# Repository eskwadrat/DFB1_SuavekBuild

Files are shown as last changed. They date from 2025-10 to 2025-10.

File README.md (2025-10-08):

## David's Falcon Booster (DFB) with Suavek Build update - described down below in Suavek UPDATE section. 

#### An attempt to build a low-cost memory expansion and accelerator board for the Atari Falcon.

The primary goals of the project are to:

* Be a plug-in board requiring no soldering on the Falcon;
* Increase available RAM beyond the 14MB the stock Falcon can be expanded to;
* Be low cost;
* Provide some acceleration;
* Allow the PSU to remain in the case;
* Be open source.

Some development narration on this project is provided in the [Wiki](https://github.com/dh219/DFB/wiki).

Firmware source (ISE), board design files (KiCAD) and any source for support programs are published at each release.

#### Capabilities

As of 2024 the published firmware supports 64 (2x32) or 128 (2x64) MB of TT-RAM.

It supports only a PGA128 MC68030. The board has been tested between 32 and 50MHz with the CPU normally being the limiting factor.

The FPU is optional and can be run at half the CPU speed, or with an independent oscillator. This is configured by a resistor placement choice.

The Falcon's on-board FPU, if fitted, should be removed to prevent bus conflicts.

---

*Copyright 2020-24 D Henderson, released under GPL2.0*

#### Suavek UPDATE 

This is David Henderson Falcon accelerator design for Atari Falcon 030. 
Original design Github repository link: https://github.com/dh219/DFB

This fork contains David’s KiCad files for the PCB design, in which I slightly modified the silkscreen layer to make selected reference designators visible outside the component footprints. This ensures that when the board is assembled, the markings remain clearly visible.

Additional silkscreen cleanup involved removing silkscreen covering certain through-hole pads. I have no idea how these ended up there. Normally, such markings are flagged and removed by a CAM engineer at the PCB shop during fabrication if present, but I decided to correct them directly in the source file to avoid the risk of them being left in place. If manufactured that way, the silkscreen paint could cover plated-through holes, rendering the board unusable for assembly.

No other design changes were made to the original DFB1 board. There were no copper or component modifications of any kind.

The fork also includes a CPLD modification I introduced and tested to enable “dual boot” functionality for the DFB1’s on-board Flash.
Boot selection is controlled using the OPTION1 section of the J2 jumper. When the jumper is closed, the computer boots from Flash Bank 0 (A19 = 0); when open, it boots from Bank 1 (A19 = 1).
This mod is achieved by patching the original Verilog code for the CPLD, where I repurposed the OPTION1 jumper from its original RAM-size selection function to serve the new dual-boot feature. Since my DFB1 build is equipped with 64 MB of physical RAM, the jumper setting is no longer needed to select memory size as it would not change the installed RAM on the PCB. Therefore, we lose no functionality by repurposing the Option1 jumper and instead gain a useful new feature.

Steve Suavek, 10/08/2025
______________

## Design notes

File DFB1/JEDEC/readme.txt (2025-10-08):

This mod enables use of A19 address line to switch two 512kB banks of 1MB Flash on board of DFB1 to have dual boot. 

The mod is using Options1 jumper which was repurposed from selecting 64/128MB Fast RAM size to switching Flash ROM boot banks.

To bypass 64/128MB Option1 switch, I created two separate .jed files to flash in CPLD with 64MB or 128MB RAM installed on the DFB1 board. 

With this mod Option1 jumper allows to switch banks. It can be wired to external switch for user convenience. 

_________________________________________
mod by Steve Suavek, 2025-10-07

I am not responsible for any damages to your equipment or software if you decided to use this mod. All responsibility to validate this mod is upon you if you choose to use it. Thanks.

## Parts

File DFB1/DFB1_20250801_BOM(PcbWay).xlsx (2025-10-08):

 |  |  | DFB1_20250801 BOM
Item # | *Designator | *Qty | Manufacturer | *Mfg Part # | Description / Value | *Package/Footprint | Type | Your Instructions / Notes
1 | C22,C10,C19,C1,C3 | 5 | KEMET | C0805C106K4PACTU | CAP CER 10UF 10% 16V X5R 0805 | 0805 | SMT | or similar w/same parametrers listed in description
2 | C25,C24,C11,C9,C8,C23,C17,C16,C15,C14,C13,C12,C20,C18,C2,C7,C6,C4 | 18 | Yageo | CC0805KRX7R9BB104 | CAP CER 0.1UF 10% 50V X7R 0805 | 0805 | SMT | or similar w/same parametrers listed in description
3 | C5 | 1 | KEMET | C0805C331J5GACTU | CAP CER 330PF 5% 50V C0G/NP0 0805 | 0805 | SMT | or similar w/same parametrers listed in description
4 | D5,D4,D3,D2,D1 | 5 | Osram | LS R976-NR-1-0-20-R18 | LED RED DIFFUSED 100mcd 0805 SMD | 0805 | SMT | or similar w/same parametrers listed in description
5 | IC2,IC1 | 2 | ISSI | IS42S16160G-7TLI | IC DRAM 256MBIT PAR 54TSOP II | TSOP-II-54 | SMT | for 64MB Fast RAM
6 | IC6,IC5,IC4,IC3 | 4 | TI | SN74CB3T3245PW | IC BUS SWITCH 8 X 1:1 20-TSSOP | TSSOP-20 | SMT
7 | R10,R9,R8,R7,R6 | 5 | Stackpole | RNCP0805FTD1K00 | RES 1K OHM 1% 1/4W 0805 | 0805 | SMT | or similar w/same parametrers listed in description
8 | R12 | 1 | Stackpole | RNCP0805FTD4K75 | RES 4.75K OHM 1% 1/4W 0805 | 0805 | SMT | or similar w/same parametrers listed in description
9 | R15,R14,R13 | 3 | Stackpole | RNCP0805FTD10K0 | RES 10K OHM 1% 1/4W 0805 | 0805 | SMT | or similar w/same parametrers listed in description
10 | R18,R1,R20,R19,R16 | 5 | Stackpole | RNCP0805FTD33R2 | RES 33.2 OHM 1% 1/4W 0805 | 0805 | SMT | or similar w/same parametrers listed in description
11 | R3,R2 | 2 | Stackpole | RNCP0805FTD2K21 | RES 2.21K OHM 1% 1/4W 0805 | 0805 | SMT | or similar w/same parametrers listed in description
12 | RN7,RN6,RN5,RN4,RN2,RN1 | 6 | Yageo | TC164-JR-0710KL | RES ARRAY 4 RES 10K OHM 1206 | 1206, Concave | SMT | or similar w/same parametrers listed in description
13 | U1 | 1 | TI | LM1117MP-3.3/NOPB | IC REG LINEAR 3.3V 800MA SOT-223 | SOT-223 | SMT
14 | U4 | 1 | AMD | XC95288XL-10TQG144I | IC CPLD 288MC 10NS 144TQFP | TQFP144 | SMT
15 | U5 | 1 | Macronix | MX29F800CBTI-70G | IC FLASH 8MBIT PARALLEL 48TSOP | TSOP-I-48 | SMT
Need a quick and accurante quote? Need an efficient production? Please read SMT Ordering Necessary Files & Info in 1 minute. Thank you very much! (https://www.pcbway.com/smt_ordering_guide.html)
Click for Instructions on How to Create a BOM (https://www.pcbway.com/blog/PCB_Assembly/How_to_Build_a_BOM__Bill_Of_Materials_.html)

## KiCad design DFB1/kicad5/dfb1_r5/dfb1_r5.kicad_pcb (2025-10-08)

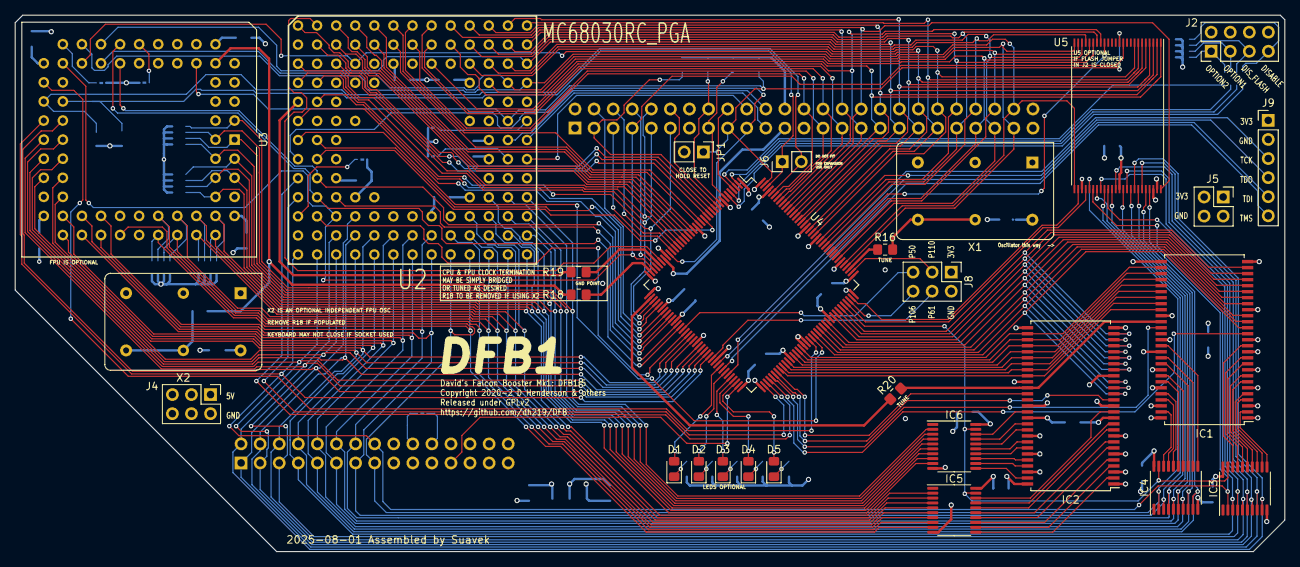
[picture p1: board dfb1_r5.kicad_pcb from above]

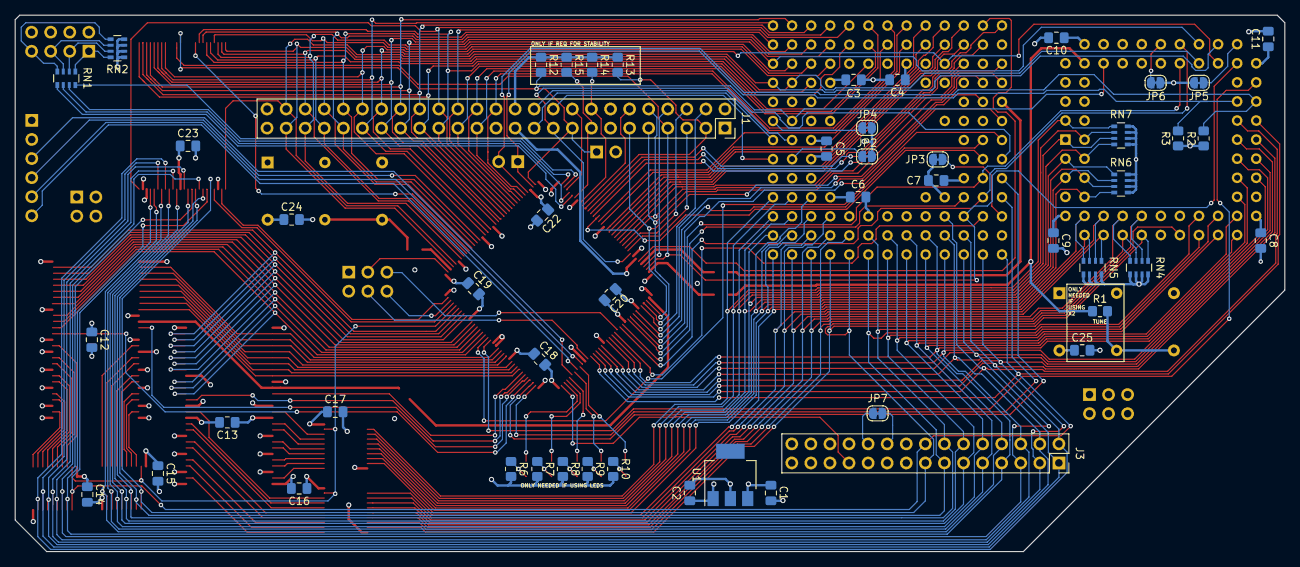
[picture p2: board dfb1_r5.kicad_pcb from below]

Board: 4 copper layers, 169.0 x 71.4 mm, 79 parts (51 on the bottom side), 204 nets.

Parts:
C1, C3, C10, C19, C22: 10u; C_0805_2012Metric_Pad1.18x1.45mm_HandSolder
C2, C4, C6, C7, C8, C9, C11, C12, C13, C14, C15, C16, C17, C18, C20, C23, C24, C25: 100n; C_0805_2012Metric_Pad1.18x1.45mm_HandSolder
C5: 330p; C_0805_2012Metric_Pad1.18x1.45mm_HandSolder
D1, D2, D3, D4, D5: LED; LED_0805_2012Metric_Pad1.15x1.40mm_HandSolder
IC1, IC2: IS42S16320D-7TL; TSOP-II-54_22.2x10.16mm_P0.8mm
IC3, IC4, IC5, IC6: SN74CB3T3245PW; TSSOP-20_4.4x6.5mm_P0.65mm
J1: Conn_01x50; PinSocket_2x25_P2.54mm_Vertical
J2: Conn_02x04_Odd_Even; PinHeader_2x04_P2.54mm_Vertical
J3: Conn_01x30; PinSocket_2x15_P2.54mm_Vertical
J4, J8: Conn_02x03_Odd_Even; PinHeader_2x03_P2.54mm_Vertical
J5: Conn_02x02_Odd_Even; PinHeader_2x02_P2.54mm_Vertical
J6: Conn_01x02_Female; PinHeader_1x02_P2.54mm_Vertical
J9: Conn_01x06_Male; PinHeader_1x06_P2.54mm_Vertical
JP1: Jumper_NO_Small; PinHeader_1x02_P2.54mm_Vertical
JP2, JP3, JP4, JP5, JP6, JP7: Jumper_NC_Small; SolderJumper-2_P1.3mm_Bridged_RoundedPad1.0x1.5mm_DAVID
R1, R16, R18, R19, R20: 33R NOMINAL; R_0805_2012Metric_Pad1.20x1.40mm_HandSolder
R2, R3: 2k2; R_0805_2012Metric_Pad1.20x1.40mm_HandSolder
R6, R7, R8, R9, R10: 1k; R_0805_2012Metric_Pad1.20x1.40mm_HandSolder
R12: 4k7 OPTION; R_0805_2012Metric_Pad1.20x1.40mm_HandSolder
R13, R14, R15: 10k OPTION; R_0805_2012Metric_Pad1.20x1.40mm_HandSolder
RN1, RN2, RN4, RN5, RN6, RN7: 10K; R_Array_Convex_4x0603
U1: LM1117-3.3; SOT-223
U2: MC68030RC_PGA
U3: MC68882; PLCC-68_THT-Socket
U4: XC95288XL-10TQG144I; TQFP-144_20x20mm_P0.5mm
U5: 29F800C-TSOP-48; TSOP-I-48_18.4x12mm_P0.5mm
X1, X2: CXO_DIP14_DIP8_DUAL; Oscillator_DIP-14-DUAL

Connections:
/68030/CDIS: JP2.1, U2.H12
/68030/CIIN: JP3.1, U2.L1
/68030/FPUSIZE: JP6.1, U3.18
/68030/FPU_A0: JP5.1, U3.26
/68030/MMUDIS: JP4.1, U2.F13
/CPLD/LED1: D1.2, U4.64
/CPLD/LED2: D2.2, U4.66
/CPLD/LED3: D3.2, U4.68
/CPLD/LED4: D4.2, U4.69
/CPLD/LED5: D5.2, U4.70
/CPLD/P50: J8.5, U4.50
/CPLD/P61: J8.4, U4.61
/CPLD/P106: J8.6, U4.106
/CPLD/P110: J8.3, U4.110
/CPLD/TCK: J9.3, U4.67
/CPLD/TDI: J9.5, U4.63
/CPLD/TDO: J9.4, U4.122
/CPLD/TMS: J9.6, U4.65
/CPUBGI: J3.22, JP7.2
/CPUBGO: J3.20, JP7.1
/ENABLE_J: J2.7, RN1.4, RN2.5
/EN_ALTRAM_J: J2.3, RN1.2, RN2.7
/EN_FLASH_J: J2.5, RN1.3, RN2.6
/OPTION_J: J2.1, RN1.1, RN2.8
A0: U2.A2, U4.31
A1: J1.48, U2.C4, U3.25, U4.113, U5.25
A2: J1.47, U2.D13, U3.24, U4.112, U5.24
A3: J1.46, U2.D12, U3.23, U4.116, U5.23
A4: J1.45, U2.C13, U3.22, U4.115, U5.22
A5: J1.44, U2.C12, U4.119, U5.21
A6: J1.43, U2.D11, U4.117, U5.20
A7: J1.42, U2.B13, U4.121, U5.19
A8: J1.41, U2.B12, U4.120, U5.18
A9: J1.40, U2.C11, U4.124, U5.8
A10: J1.39, U2.A13, U4.125, U5.7
A11: J1.38, U2.C10, U4.126, U5.6
A12: J1.37, U2.B11, U4.128, U5.5
A13: J1.36, U2.A12, U4.129, U5.4
A14: J1.35, U2.B10, U4.130, U5.3
A15: J1.34, U2.A11, U4.131, U5.2
A16: J1.33, U2.B9, U4.132, U5.1
A17: J1.32, U2.A10, U4.134, U5.48
A18: J1.31, U2.C8, U4.133, U5.17
A19: J1.30, U2.A9, U4.135
A20: J1.29, U2.B8, U4.136
A21: J1.28, U2.A8, U4.137
A22: J1.27, U2.B7, U4.138
A23: J1.26, U2.A7, U4.139
A24: U2.A6, U4.16
A25: U2.B6, U4.17
A26: U2.A5, U4.19
A27: U2.B5, U4.20
A28: U2.A4, U4.21
A29: U2.B4, U4.22
A30: U2.A3, U4.23
A31: U2.B3, U4.24
BA0: IC1.20, IC2.20, U4.96
BA1: IC1.21, IC2.21, U4.97
BMODE: J1.12, U4.10
CLKOSC: R16.1, U4.111
CPUCLK: R19.2, U2.E1
D0: IC6.2, RN7.1, U2.K13, U3.3
D1: IC6.3, RN7.2, U2.K12, U3.2
D2: IC6.4, RN7.3, U2.L13, U3.1
D3: IC6.6, RN7.4, U2.M13, U3.68
D4: IC6.5, RN6.1, U2.L12, U3.67
D5: IC6.7, RN6.3, U2.K11, U3.66
D6: IC6.8, RN6.2, U2.M12, U3.65
D7: IC6.9, RN6.4, U2.L11, U3.64
D8: IC5.2, RN5.4, U2.N13, U3.62
D9: IC5.3, RN5.3, U2.M11, U3.60
D10: IC5.4, RN5.2, U2.L10, U3.59
D11: IC5.5, RN5.1, U2.N12, U3.58
D12: IC5.6, RN4.4, U2.M10, U3.57
D13: IC5.7, RN4.3, U2.N11, U3.56
D14: IC5.8, RN4.2, U2.M9, U3.55
D15: IC5.9, RN4.1, U2.N10, U3.54
D16: IC4.2, J3.15, U2.N9, U3.50, U5.29
D17: IC4.4, J3.14, U2.M8, U3.49, U5.31
D18: IC4.3, J3.13, U2.N8, U3.48, U5.33
D19: IC4.5, J3.12, U2.N7, U3.47, U5.35
D20: IC4.6, J3.11, U2.M7, U3.46, U5.38
D21: IC4.7, J3.10, U2.N6, U3.45, U5.40
D22: IC4.8, J3.9, U2.M6, U3.44, U5.42
D23: IC4.9, J3.8, U2.N5, U3.42, U5.44
D24: IC3.3, J3.7, U2.M5, U3.40, U4.52, U5.30
D25: IC3.5, J3.6, U2.N4, U3.39, U4.53, U5.32
D26: IC3.4, J3.5, U2.N3, U3.38, U4.54, U5.34
D27: IC3.7, J3.4, U2.M4, U3.37, U4.56, U5.36
D28: IC3.6, J3.3, U2.N2, U3.36, U4.57, U5.39
D29: IC3.9, J3.2, U2.M3, U3.35, U4.58, U5.41
D30: IC3.8, J3.1, U2.L4, U3.34, U4.59, U5.43
D31: IC3.2, J3.16, U2.N1, U3.33, U4.60, U5.45
DQM0: IC1.15, U4.76
DQM1: IC1.39, U4.77
DQM2: IC2.15, U4.78
DQM3: IC2.39, U4.79
ENABLE: RN1.5, U4.6
EN_ALTRAM: RN1.7, U4.2
EN_FLASH: RN1.6, U4.5
FC0: J1.11, U2.D2, U4.39
FC1: J1.10, U2.C1, U4.25
FC2: J1.9, U2.D1, U4.40
FPUCLK: R1.1, R18.2, U3.11
GND: C1.2, C2.2, C3.2, C4.2, C5.2, C6.2, C7.2, C8.2, C9.2, C10.2, C11.2, C12.2, C13.2, C14.2, C15.2, C16.2, C17.2, C18.2, C19.2, C20.2, C22.2, C23.2, C24.2, C25.2, IC1.6, IC1.12, IC1.19, IC1.28, IC1.41, IC1.46, IC1.52, IC1.54, IC2.6, IC2.12, IC2.19, IC2.28, IC2.41, IC2.46, IC2.52, IC2.54, IC3.10, IC4.10, IC5.10, IC6.10, J1.1, J1.2, J2.2, J2.4, J2.6, J2.8, J3.17, J3.18, J3.19, J4.2, J4.4, J4.6, J5.2, J5.4, J8.2, J9.2, JP1.2, R6.2, R7.2, R8.2, R9.2, R10.2, U1.1, U2.C5, U2.C7, U2.C9, U2.E3, U2.E11, U2.F3, U2.G3, U2.G11, U2.J3, U2.J11, U2.L5, U2.L7, U2.L8, U2.L9, U3.5, U3.6, U3.7, U3.8, U3.9, U3.12, U3.14, U3.19, U3.30, U3.41, U3.51, U3.63, U4.18, U4.29, U4.36, U4.47, U4.62, U4.72, U4.89, U4.90, U4.99, U4.108, U4.114, U4.123, U4.144, U5.27, U5.46, X1.4, X1.7, X2.4, X2.7
KHZ500: J3.23, U4.71
MA0: IC1.23, IC2.23, U4.100
MA1: IC1.24, IC2.24, U4.101
MA2: IC1.25, IC2.25, U4.102
MA3: IC1.26, IC2.26, U4.103
MA4: IC1.29, IC2.29, U4.88
MA5: IC1.30, IC2.30, U4.87
MA6: IC1.31, IC2.31, U4.86
MA7: IC1.32, IC2.32, U4.85
MA8: IC1.33, IC2.33, U4.83
MA9: IC1.34, IC2.34, U4.82
MA10: IC1.22, IC2.22, U4.98
MA11: IC1.35, IC2.35, U4.81
MA12: IC1.36, IC2.36, U4.80
MD0: IC2.2, IC5.11
MD1: IC2.4, IC5.12
MD2: IC2.5, IC5.13
MD3: IC2.7, IC5.14
MD4: IC2.8, IC5.15
MD5: IC2.10, IC5.16
MD6: IC2.11, IC5.17
MD7: IC2.13, IC5.18
MD8: IC2.42, IC6.18
MD9: IC2.44, IC6.17
MD10: IC2.45, IC6.16
MD11: IC2.47, IC6.15
MD12: IC2.48, IC6.14
MD13: IC2.50, IC6.13
MD14: IC2.51, IC6.12
MD15: IC2.53, IC6.11
MD16: IC1.2, IC3.11
MD17: IC1.4, IC3.12
MD18: IC1.5, IC3.13
MD19: IC1.7, IC3.14
MD20: IC1.8, IC3.15
MD21: IC1.10, IC3.16
MD22: IC1.11, IC3.17
MD23: IC1.13, IC3.18
MD24: IC1.42, IC4.11
MD25: IC1.44, IC4.12
MD26: IC1.45, IC4.13
MD27: IC1.47, IC4.14
MD28: IC1.48, IC4.15
MD29: IC1.50, IC4.16
MD30: IC1.51, IC4.17
MD31: IC1.53, IC4.18
unnamed: D1.1, R10.1
unnamed: D2.1, R9.1
unnamed: D3.1, R8.1
unnamed: D4.1, R7.1
unnamed: D5.1, R6.1
unnamed: R1.2, X2.8, X2.11
unnamed: R16.2, X1.8, X1.11
unnamed: R18.1, U4.35
unnamed: R19.1, U4.32
unnamed: R20.1, U4.38
OPTION: RN1.8, U4.3
RAMCLK: IC1.38, IC2.38, R20.2
ROM_A19: U4.118, U5.16
SIZ0: U2.L2, U4.51
SIZ1: U2.K3, U4.48
VCC: C1.1, C3.1, C4.1, C5.1, C6.1, C7.1, C8.1, C9.1, C10.1, C11.1, C23.1, C24.1, C25.1, J1.24, J1.25, J3.28, J3.29, J3.30, J4.1, J4.3, J4.5, JP2.2, JP3.2, JP4.2, JP5.2, JP6.2, R2.1, R3.1, R12.1, R13.1, R14.1, R15.1, RN4.5, RN4.6, RN4.7, RN4.8, RN5.5, RN5.6, RN5.7, RN5.8, RN6.5, RN6.6, RN6.7, RN6.8, RN7.5, RN7.6, RN7.7, RN7.8, U1.3, U2.C6, U2.D4, U2.D10, U2.F2, U2.F11, U2.H3, U2.H11, U2.K4, U2.K10, U2.L6, U3.10, U3.16, U3.17, U3.27, U3.43, U3.52, U3.53, U3.61, U5.37, U5.47, X1.14, X2.14
VCC3: C2.1, C12.1, C13.1, C14.1, C15.1, C16.1, C17.1, C18.1, C19.1, C20.1, C22.1, IC1.1, IC1.3, IC1.9, IC1.14, IC1.27, IC1.37, IC1.43, IC1.49, IC2.1, IC2.3, IC2.9, IC2.14, IC2.27, IC2.37, IC2.43, IC2.49, IC3.20, IC4.20, IC5.20, IC6.20, J5.1, J5.3, J8.1, J9.1, RN2.1, RN2.2, RN2.3, RN2.4, U1.2, U4.1, U4.8, U4.37, U4.42, U4.55, U4.73, U4.84, U4.109, U4.127, U4.141
XCPUCLK: J1.23, U4.30
XR~W: J1.7, U2.L3, U3.28, U4.34, U5.11
~AS: U2.J2, U3.21, U4.46
~AVEC: U2.E2, U4.43
~BERR: J1.19, U2.H1, U4.28
~BGK: U2.C3, U4.14
~BG: U2.B2, U4.12
~BOE: IC3.19, IC4.19, IC5.19, IC6.19, U4.104
~BR: U2.A1, U4.13
~CAS: IC1.17, IC2.17, U4.94
~CBACK: U2.J1, U4.75
~CBREQ: U2.K1, U4.74
~DSACK0: U2.F1, U4.45
~DSACK1: U2.G2, U4.44
~DS: U2.K2, U3.20, U4.49
~FPUCS: U3.29, U4.91
~FPUDSACK0: J6.2, R2.2, U3.31, U4.140
~FPUDSACK1: J6.1, R3.2, U3.32, U4.142
~HLT: U2.H2, U4.15
~IPL0: J1.20, U2.H13
~IPL1: J1.21, U2.G13
~IPL2: J1.22, U2.G12
~LDS: J1.5, U4.27
~RAMWE: IC1.16, IC2.16, U4.93
~RAS: IC1.18, IC2.18, U4.95
~ROMCE: U4.107, U5.26
~ROMOE: U4.105, U5.28
~RST: J1.17, JP1.1, R12.2, U2.F12, U3.13, U4.143, U5.12
~STERM: U2.G1, U4.92
~UDS: J1.6, U4.26
~XAS: J1.4, U4.41
~XBGK: J1.3, R13.2, U4.11
~XBG: J1.15, R15.2, U4.7
~XBR: J1.16, R14.2, U4.9
~XDTACK: J1.8, U4.33
~XHALT: J1.18, U4.4

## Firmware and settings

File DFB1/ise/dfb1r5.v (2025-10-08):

`timescale 1ns / 1ps

/* DFB1 is Copyright 2019-21 D Henderson.
/* SDRAM controller is based on work Copyright S J Leary 
/* Released under the terms of the GPLv2
/* See LICENCE.TXT
*/

module dfb1r5(

	input [31:0]    	A,
	input [2:0] 	FC,
	inout	BERR,
	input   			XCPUCLK,
	output FPUCLK,
	input OPTION1,
	input OPTION2,
	output XHALT,
	input EN_FLASH,
	input ENABLE,
	input			XBG,
	inout			XBR,
	output BMODE,
	inout			XBGK,
	input				BG,
	output			BR,
	output			BGK,
	output  			HLT,
	input P142,
	input				RST,
	output   		CPUCLK,
	inout XDTACK,
	input XRW,
	output  			CLKRAM,
	output			UDS,
	output			LDS,
	inout				XAS,
	output AVEC,
	inout [1:0] 	DSACK,
	input [1:0] FPUDSACK,
	input				AS,
	input [1:0] 	SIZ,
	input				DS,
	output ROM_A19,
	inout [7:0] D,
	output [1:5] LED,

	output P50,	//CLK
	output P61,	// MOSI
	input P106, // MISO
	output P110, // CS

	input   			CLKOSC,
	input KHZ500,
	input CBREQ,
	output			CBACK,
	output [3:0] 	DQM,
	output [12:0]  MA,
	output FPUCS,
	output			STERM,
	output			RAMWE,
	output			CAS,
	output			RAS,
	output [1:0] 	BA,
	output BOE,
	output ROMOE,
	output ROMCE

);


// EmuTOS doesn't seem to like booting at full speed -- give it time to get started.
reg [20:0] resetcounter = 'd0;
always @( negedge KHZ500) begin
	if( ~RST ) begin
		resetcounter <= 'd0;
	end else begin
		resetcounter <= resetcounter + 'd1;
	end
end

wire speedallowtrigger = resetcounter[20];
wire resetblock; // active low
FDCP latch_resetblock( .D( 1'b1 ), .C( ~speedallowtrigger ), .CLR( ~RST ), .PRE( 1'b0 ), .Q( resetblock ) );

/* config section */
reg [7:0] reg_dfb = 8'b11111101;
reg [7:0] reg_spi = 8'b11111111; // [7] = busy; [6] = read req; [5-2] reserved ; [1] = low speed clock ; [0] = CS

reg [7:0] d_in;
reg [7:0] reg_spi_write_data = 'hFF;
reg [7:0] reg_spi_read_data = 'hFF;

reg spi_xfer = 1'b0; // active high
reg [5:0] spi_xfer_state = 'd0;

reg spi_clk = 1'b0;
reg spi_mosi = 1'b1;

reg DISABLE = 1'b1;
reg DISABLE_FLASH_ROM = 1'b1;
reg DISABLE_ALTRAM = 1'b1;
reg DISABLE_FAST = 1'b1;
always @(posedge RST) begin
	DISABLE <= ENABLE;
	DISABLE_FLASH_ROM <= EN_FLASH;
	DISABLE_FAST <= OPTION2;
//	DISABLE <= reg_dfb[0];
//	DISABLE_FLASH_ROM <= reg_dfb[1];
end
/*
always @(*) begin
	DISABLE_FAST <= reg_dfb[3];
end
*/
wire [1:0] FPUSPEED = reg_dfb[5:4];

wire HIGHZ;

wire [3:0] state;

wire hlt;
/* optimise */
ARBDFB1 arbdfb1 (
	.DISABLED( DISABLE ),
	.CLOCK(~XCPUCLK),
	._RST(RST),
	._XAS(XAS),
	._XBR(XBR),
	._XBG(XBG),
	._XBGK(XBGK),
	._AS(AS),
	._BG(BG),

	._BR(BR),
	._BGK(BGK),
	._HLT(HLT),
	._XHALT(XHALT),
	.HIGHZ(HIGHZ),
	
	.STATE(state)
);

wire fpu = AS | {FC,A[19:16]} != 7'b1110010; // co-processor decode
wire ttram_access = ~DISABLE_ALTRAM | ( A[27:24] == 'hF | A[27:24] == 'h0 );
wire rom_access =  ~DISABLE_FLASH_ROM | A[27:20] != 8'h0E; // Flash ROM
wire dsp_access = A[27:8] != 20'h0FFA2;

// original code line below
//wire berr_ram = OPTION1 ? A[26:24] != 3'b101 : A[27:24] != 4'b1001; // 128MB / 64 switch

// Suavek dual boot mod added on 2025-10-07
wire berr_ram = A[26:24] != 3'b101; // 64MB for 2025 Suavek DFB1 build
//wire berr_ram = A[27:24] != 4'b1001; // 128MB suitable 

wire reg_access = A[31:4] != 28'h00F1DFB; // our register F1DFxx
reg flash_access = 1'b1;
always @(negedge XAS ) begin
	flash_access <= ~( ( A[23:20] == 4'hF ) & ( ( A[19:17] == 3'b100 ) | ( { A[19], |A[18:17] } == 2'b01 ) ) ); // F20000-F9FFFF -- F && ( 8/9 || 2-7 )
end


reg CLKOSC_2 = 1'b1;
always @( posedge CLKOSC ) begin
	CLKOSC_2 <= ~CLKOSC_2;
end

// we don't allow switching from slow back to fast for two clock cycles after XDTACK -- this gives full ST ram access speed for negligible TTRAM overhaed
wire [1:0] xdtack_delay;
FDCP ff_xdtack1( .D( XDTACK ), .C( ~XCPUCLK), .CLR( 1'b0 ), .PRE( 1'b0 ), .Q(xdtack_delay[0]) );
FDCP ff_xdtack2( .D( xdtack_delay[0] ), .C( ~XCPUCLK  ), .CLR( 1'b0 ), .PRE( 1'b0 ), .Q(xdtack_delay[1]) );
wire clockholdoff = &xdtack_delay[1:0];
wire lowspeed = DISABLE_FAST & resetblock & fpu & ( AS | ~ttram_access | ~rom_access ) & clockholdoff ; // low active (rom access here too)
//wire lowspeed = DISABLE_FAST & resetblock & ( AS | ~ttram_access | ~rom_access | ~fpu ) & clockholdoff ; // low active (rom access here too)

wire CPUCLK_D;
wire clock_block;

clockmux cm1 ( .clk0( CLKOSC ), 
	.clk1( XCPUCLK  ), 
	.select( lowspeed ),
	.active1( clock_block ),
	.out_clock( CPUCLK_D ) 
);

/* RAM */

sdram SDRAM (
	// inputs
	.RESET(RST),

	.CLKCPU (CPUCLK_D),
	.CLK    (CPUCLK_D),

	.A(A),
	.SIZ(SIZ),

	.AS30(AS),
	.RW30(XRW),
	.DS30(DS),
	.CBREQ(CBREQ),

	// outputs
	.ACCESS(ttram_access),
	.CBACK(CBACK),
	.STERM(STERM),

	.ARAM(MA),
	.BA(BA),

	.CAS(CAS),
	.RAS(RAS),

	.DQM(DQM),

	.RAMWE(RAMWE)
);

/*******/


wire [5:0] AS_DELAY;
FDCP ff_asdly0( .D(AS), .C( ~CPUCLK ), .CLR(1'b0), .PRE( AS ), .Q(AS_DELAY[0]) );          // timings as per 50MHz
FDCP ff_asdly1( .D(AS_DELAY[0]), .C( ~CPUCLK ), .CLR(1'b0), .PRE( AS ), .Q(AS_DELAY[1]) ); // 20ns
FDCP ff_asdly2( .D(AS_DELAY[1]), .C( ~CPUCLK ), .CLR(1'b0), .PRE( AS ), .Q(AS_DELAY[2]) ); // 40ns
FDCP ff_asdly3( .D(AS_DELAY[2]), .C( ~CPUCLK ), .CLR(1'b0), .PRE( AS ), .Q(AS_DELAY[3]) ); // 60ns // this might be being a bit naughty -- change to [4] if unstable
FDCP ff_asdly4( .D(AS_DELAY[3]), .C( ~CPUCLK ), .CLR(1'b0), .PRE( AS ), .Q(AS_DELAY[4]) ); // 80ns
FDCP ff_asdly5( .D(AS_DELAY[4]), .C( ~CPUCLK ), .CLR(1'b0), .PRE( AS ), .Q(AS_DELAY[5]) ); // 100ns


// synthesise flash xdtack
wire [1:0] flash_xas_delay;
FDCP ff_flash_xas_delay1( .D(  XAS | (flash_access&reg_access) ), 				.C( ~XCPUCLK ), .PRE( XAS ), .CLR( 1'b0 ), .Q( flash_xas_delay[0] ) );
FDCP ff_flash_xas_delay2( .D(  flash_xas_delay[0] ), 				.C( ~XCPUCLK ), .PRE( XAS ), .CLR( 1'b0 ), .Q( flash_xas_delay[1] ) );
wire FLASH_DTACK = flash_xas_delay[1];

assign BOE = 1'b0; //ttram_access | AS;


reg AVECCYCLE = 1'b1;
always @(negedge AS) begin
	AVECCYCLE <= ( FC[2:0] != 3'b111 | A[19:16] != 4'b1111 ) | ( A[3:1] != 'd2 && A[3:1] != 'd4 );
end

wire [2:0] oldxdtack;
FDCP ff_xdtackdly1( .D( XDTACK ), .C( XCPUCLK ), .CLR(1'b0), .PRE( 1'b0 ), .Q(oldxdtack[0]) );
FDCP ff_xdtackdly2( .D(oldxdtack[0]), .C( XCPUCLK ), .CLR(1'b0), .PRE( 1'b0 ), .Q(oldxdtack[1]) );
FDCP ff_xdtackdly3( .D(oldxdtack[1]), .C( XCPUCLK ), .CLR(1'b0), .PRE( 1'b0 ), .Q(oldxdtack[2]) );
wire xas_holdoff_dsp = ~dsp_access & ~oldxdtack[1] & XAS;


wire [1:0] RAM_DTACK = { XDTACK | ~dsp_access | ~AVECCYCLE, 1'b1 };
wire [1:0] ROM_DTACK = { rom_access | ( lowspeed ? AS_DELAY[4] : AS_DELAY[1] ), 1'b1 };
wire [1:0] DSP_DTACK = { 1'b1, XDTACK | dsp_access };
wire [1:0] FPU_DSACK_INT = fpu | FPUDSACK;
wire [1:0] REG_DSACK = { AS | reg_access, 1'b1 }; // only really an 8 bit port, but pretend to be 16 to keep compatibility when being read from the Falcon's motherboard in disabled state

/* direct DSACK connections */
/*
wire [1:0] DSACK_INT = ( REG_DSACK & RAM_DTACK & ROM_DTACK & DSP_DTACK & { FLASH_DTACK, 1'b1 } );
assign DSACK = fpu ? DSACK_INT : 2'bzz;
*/
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

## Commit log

2025-10-08 Update README.md
    Original document amended with description of the changes for the PCB and CPLD code.
2025-10-08 Original PCB design file with silkscreen touchup
    Original PCB design file with silkscreen touchup
    [dfb1_r5.kicad_pcb]
2025-10-08 Gerbers & Drill files with silkscreen touchup
    Gerbers & Drill with silkscreen touchup, used in Suavek's build of limited batch of 10 boards. Confirmed to be working, these are usable Gerbers for ordering at any FAB house.
2025-10-08 Add files via upload
    Pick & Place files required by FAB/PCB house if besides the blank pcb FAB you order assembly. This is SMT parts only P&P file, so no through hole parts coordinates are present in this file. This file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
2025-10-08 BOM for Automated SMT assembly for Suavek build
    Cleaned up to date BOM for Automated SMT assembly used by PCBWay for Suavek build of DFB1 accelerator limited batch of 10 boards with 64MB RAM support. Use it if you want to order SMT assembled (bird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
    [DFB1_20250801_BOM(PcbWay).xlsx]

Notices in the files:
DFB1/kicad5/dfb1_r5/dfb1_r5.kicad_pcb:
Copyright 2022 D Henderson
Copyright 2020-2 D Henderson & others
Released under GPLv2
